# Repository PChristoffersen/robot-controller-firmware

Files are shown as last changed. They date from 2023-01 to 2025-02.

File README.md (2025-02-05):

# Robot Controller

Robot controller for use with [ROS](https://www.ros.org/) 

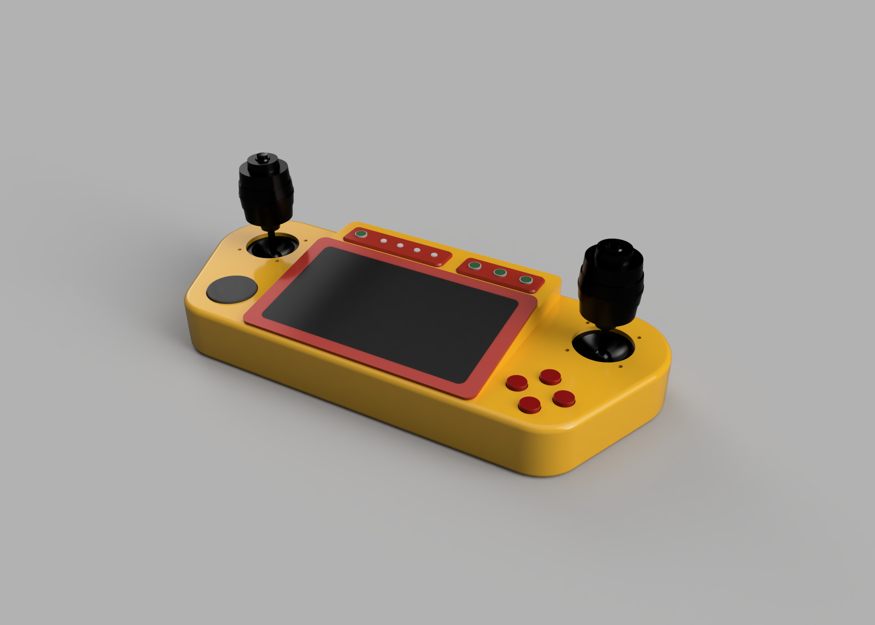
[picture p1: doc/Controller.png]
Controller

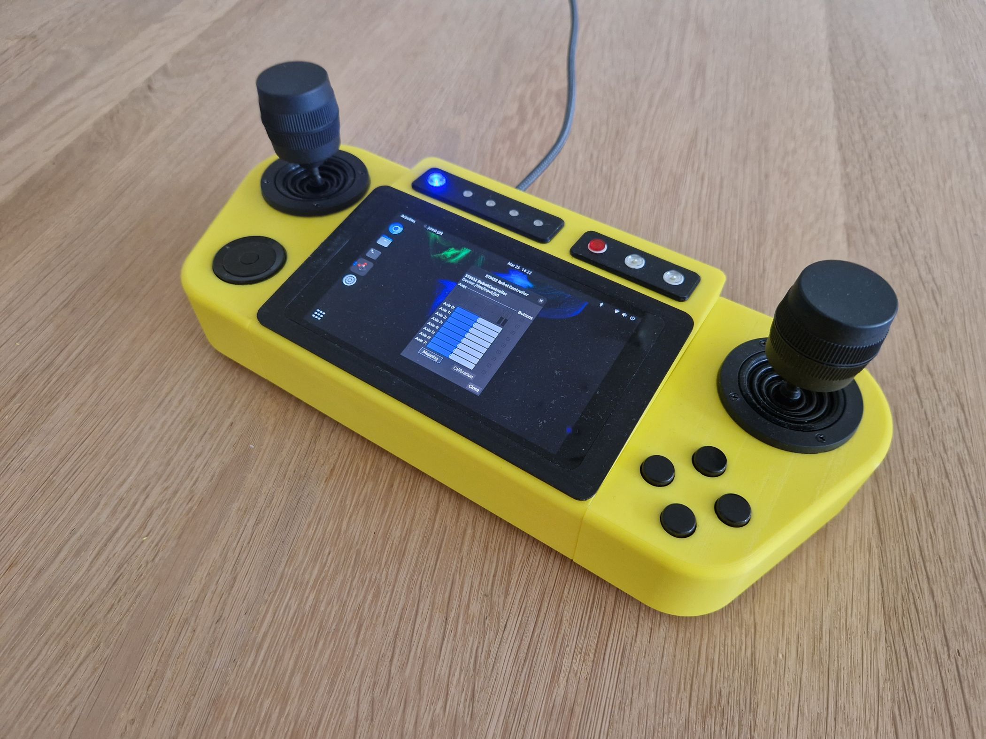
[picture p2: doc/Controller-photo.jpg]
Controller-Photo

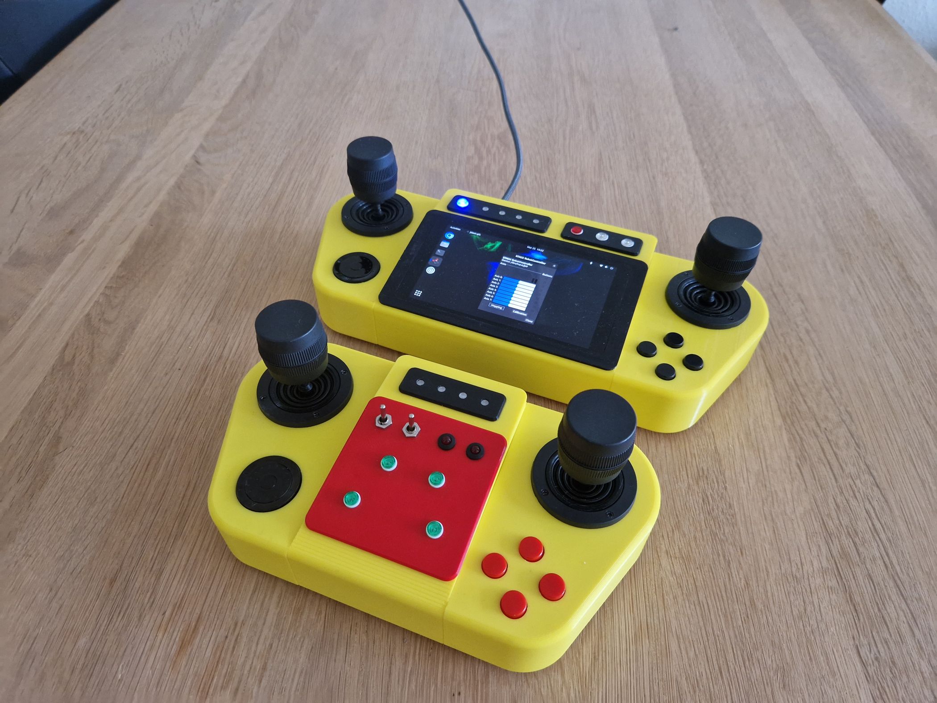
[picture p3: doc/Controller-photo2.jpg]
Controller-Photo


# Hardware

- [Waveshare 5.5inch AMOLED screen](https://www.waveshare.com/wiki/5.5inch_HDMI_AMOLED)
- Rasbperry Pi 4 or similar
- STM32F103 BluePill micro controller
- 2x JH-D300X-R4 3 Axis joystick
- [Adafruit ANO Rotary Encoder](https://learn.adafruit.com/ano-rotary-encoder)
- 4x [Sparkfun LED Tactile Button](https://www.sparkfun.com/products/10439)
- 4x [Sparkfun LED Tactile Button Breakout](https://www.sparkfun.com/products/10467)
- 4x 12mm Tactile Push button
- 4x [Adafruit RGB Smart NeoPixel](https://www.adafruit.com/product/1558)

# 3d Model

See [model](doc/model/)

# Schematic 

See documentation [schematic](doc/Schematic.pdf)

Button breakout board [gerber](doc/Button-breakout-board.zip)
Controller board [gerber](doc/Controller-board.zip)

# Lighting

TODO

# Microcontroller

## Pinout

|Function|Mode|Pin||Pin|Mode|Function|
|--- |--- |--- |---|--- |---  |--- |
| | | |USB| | | |
|ANO_SW5 |GPIO |PB12| |GND | | |
|ANO_SW4 |GPIO |PB13| |GND | | |
|ANO_SW3 |GPIO |PB14| |3V3 | | |
|ANO_SW2 |GPIO |PB15| |NRST| | |
|ANO_SW1 |GPIO |PA8 | |PB11|GPIO |EXT_OUT2 |
|DEBUG |UART1  |PA9 | |PB10|GPIO |EXT_OUT1 |
|DEBUG |UART1  |PA10| |PB1 |PWM  |LED4 |
|USB |USB |PA11| |PB0 |PWM  |LED3 |
|USB |USB |PA12| |PA7 |GPIO |EXT_IN2 |
|NEOPIXEL |PWM |PA15| |PA6 |ADC6 |VSENSE |
|ANO_ENCB |GPIO |PB3 | |PA5 |ADC5 |RIGHT_Z |
|ANO_ENCA |GPIO |PB4 | |PA4 |ADC4 |RIGHT_Y |
|EXT_IN1 |GPIO |PB5 | |PA3 |ADC3 |RIGHT_X |
|LED2 |PWM |PB6 | |PA2 |ADC2 |LEFT_Z |
|LED1 |PWM |PB7 | |PA1 |ADC1 |LEFT_Y |
|PCF8574_SCL|SCL1 |PB8 | |PA0 |ADC0 |LEFT_X |
|PCF8574_SDA|SDA1 |PB9 | |PC15|GPIO |PCF8574_INT|
| | |5V  | |PC14|GPIO |AUX |
| | |GND | |PC13| | |
| | |3V3 | |VBAT| | |

## PCF8574AN (i2c gpio expander)
|Pin|Function|
|---|---|
|0|RIGHT_X|
|1|RIGHT_Y|
|2|RIGHT_A|
|3|RIGHT_B|
|4|TOP_SW1|
|5|TOP_SW2|
|6|TOP_SW3|
|7|TOP_PWR_SW|

## Timer usage

|Timer|Usage|
|---|---|
|1|Unused|
|2|LED|
|3|PWM, led 1 and 2|
|4|PWM, led 2 and 4|

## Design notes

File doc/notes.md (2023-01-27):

# DMA1:
|Channel|Function|
|---|---|
|1|ADC1, TIM2_CH3, TIM4_CH1|
|2|USART3_TX, TIM1_CH1, TIM2_UP,  TIM3_CH3, SPI1_RX|
|3|USART3_RX, TIM1_CH2, TIM3_CH4, TIM3_UP,  SPI1_TX|
|4|USART1_TX, TIM1_CH4, TIM1_TRIG, TIM1_COM, TIM4_CH2, SPI2/I2S2_RX, |I2C2_TX
|5|USART1_RX, TIM1_UP, TIM2_CH1, TIM4_CH3, SPI2/I2S2_TX, I2C2_RX|
|6|USART2_RX, TIM1_CH3, TIM3_CH1, TIM3_TRIG, I2C1_TX|
|7|USART2_TX, TIM2_CH2, TIM2_CH4, TIM4_UP, I2C1_RX|

## Timer 1
|Timer|00|11|DMA|
|---|---|---|---|
|TIM1_CH1|PA8 |PE9 |2
|TIM1_CH2|PA9 |PE11|3
|TIM1_CH3|PA10|PE13|6
|TIM1_CH4|PA11|PE14|4

## Timer 2
|Timer|00|01|10|11|DMA|
|---|---|---|---|---|---|
|TIM2_CH1_ETR|PA0|PA15|PA0|PA15|5
|TIM2_CH2 |PA1|PB3 |PA1|PB3 |7
|TIM2_CH3 |PA2|PB10| | |1
|TIM2_CH4 |PA3|PB11| | |7

## Timer 3
|Timer|00|01|11|DMA|
|---|---|---|---|---|
|TIM3_CH1|PA6|PB4||6|
|TIM3_CH2|PA7|PB5|||
|TIM3_CH3|PB0|PC8||2|
|TIM3_CH4|PB1|PC9||3|

## Timer 4
|Timer|0|1|DMA|
|---|---|---|---|
|TIM4_CH1|PB6|PD12|1|
|TIM4_CH2|PB7|PD13|4|
|TIM4_CH3|PB8|PD14|5|
|TIM4_CH4|PB9|PD15||

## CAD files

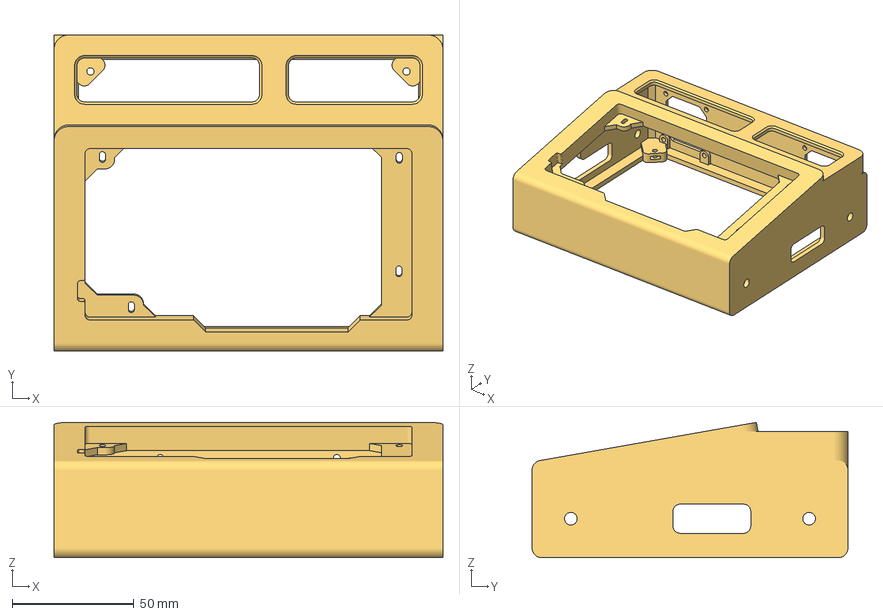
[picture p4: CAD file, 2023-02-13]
doc/model/Main.3mf
160.0 x 130.0 x 55.6 mm

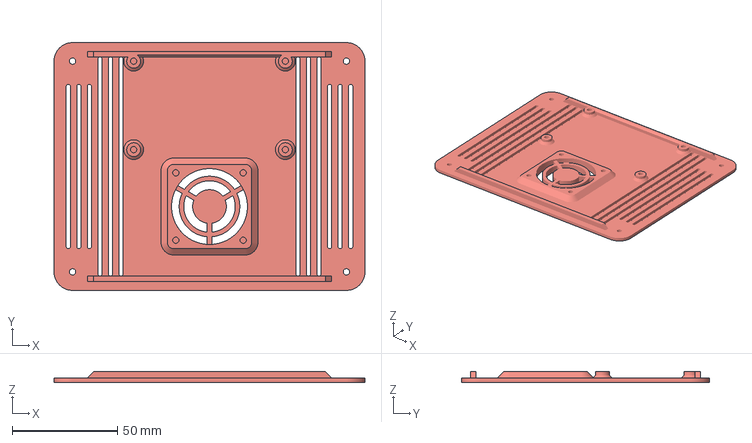
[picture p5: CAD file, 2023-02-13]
doc/model/Main Floor.3mf
147.6 x 117.6 x 5.00 mm

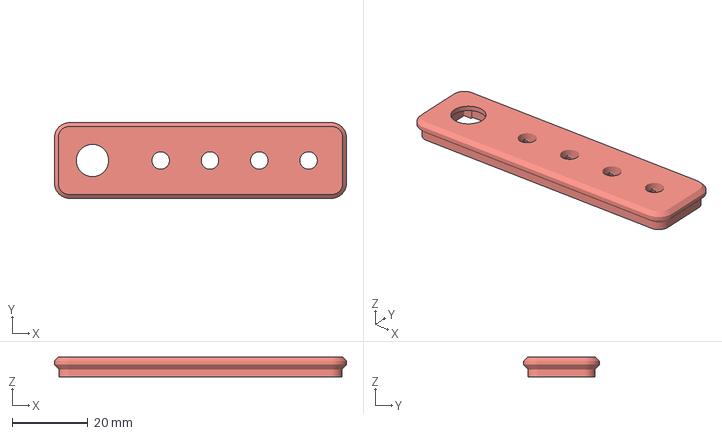
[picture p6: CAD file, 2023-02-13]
doc/model/ButtonBar Left.3mf
77.0 x 20.0 x 5.20 mm

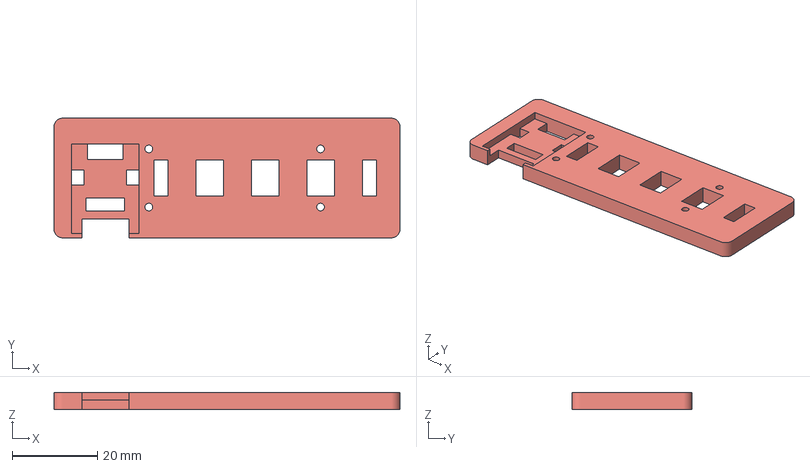
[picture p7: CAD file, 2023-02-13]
doc/model/ButtonBar Left lower.3mf
81.0 x 28.0 x 4.00 mm

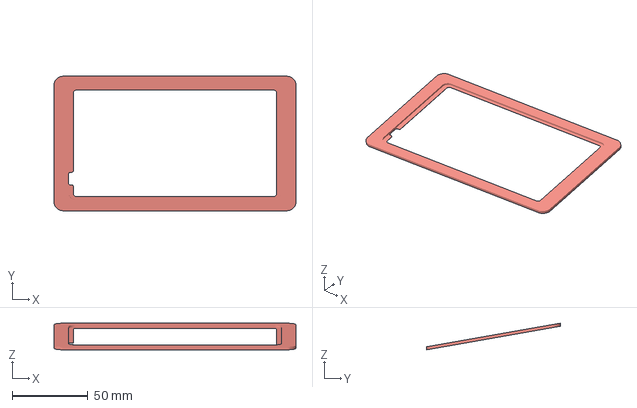
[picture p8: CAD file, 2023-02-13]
doc/model/Screen frame.3mf
160.0 x 89.0 x 17.6 mm

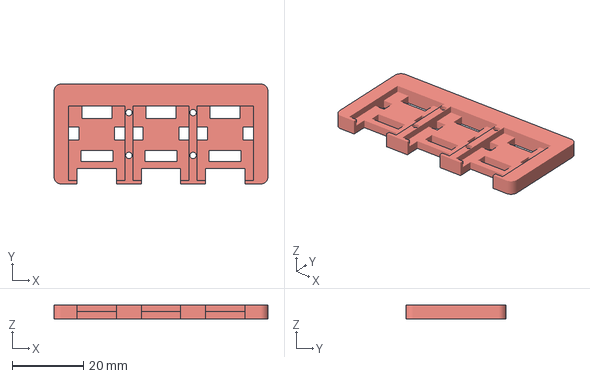
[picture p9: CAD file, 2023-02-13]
doc/model/ButtonBar Right lower.3mf
60.0 x 28.0 x 4.00 mm

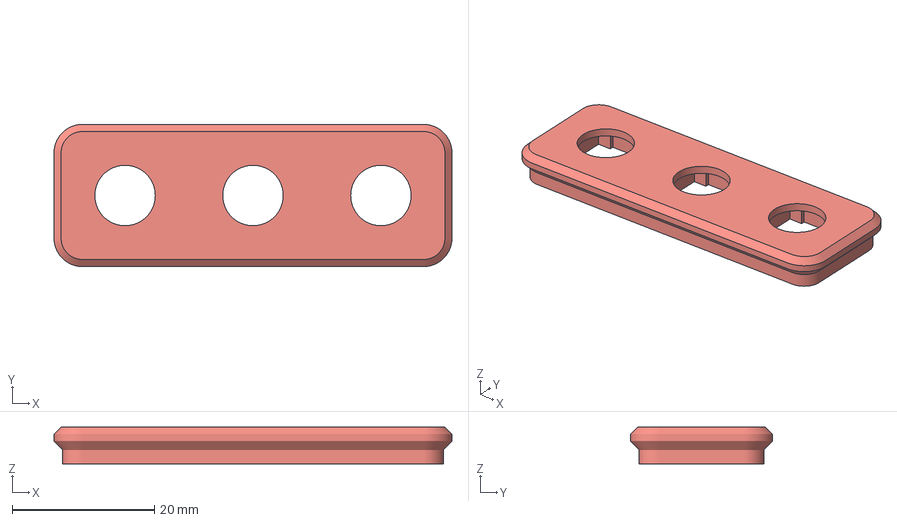
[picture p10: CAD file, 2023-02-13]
doc/model/ButtonBar Right.3mf
56.0 x 20.0 x 5.20 mm

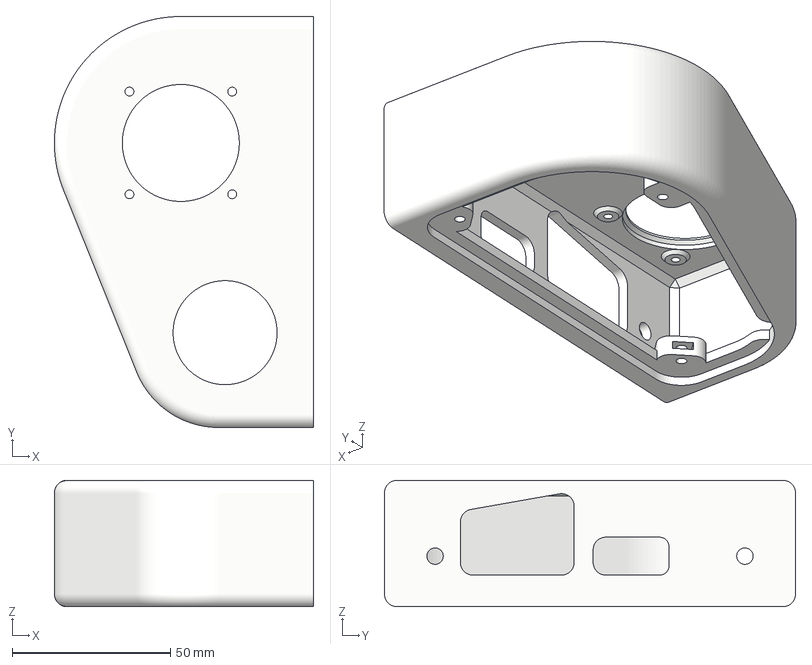
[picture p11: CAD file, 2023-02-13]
doc/model/Left Pod.3mf
82.0 x 130.0 x 40.0 mm

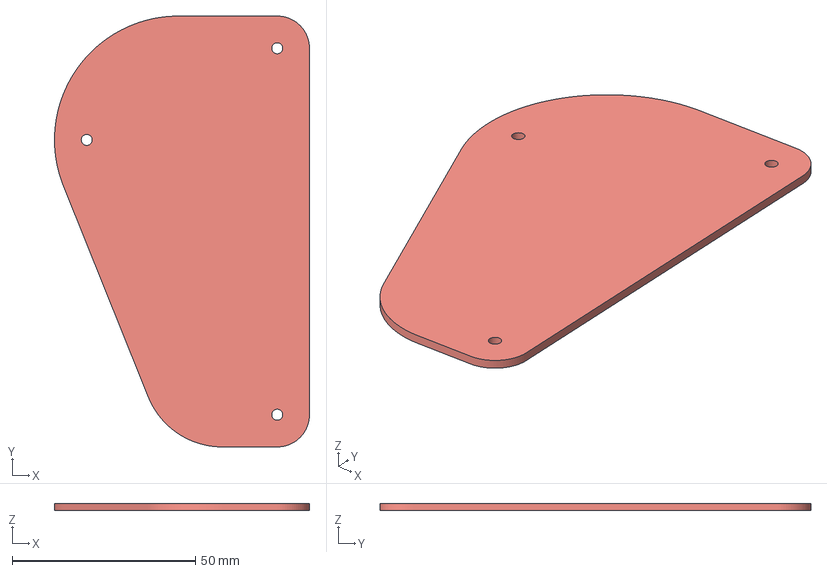
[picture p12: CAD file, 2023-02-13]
doc/model/Left Floor.3mf
69.6 x 117.6 x 2.00 mm

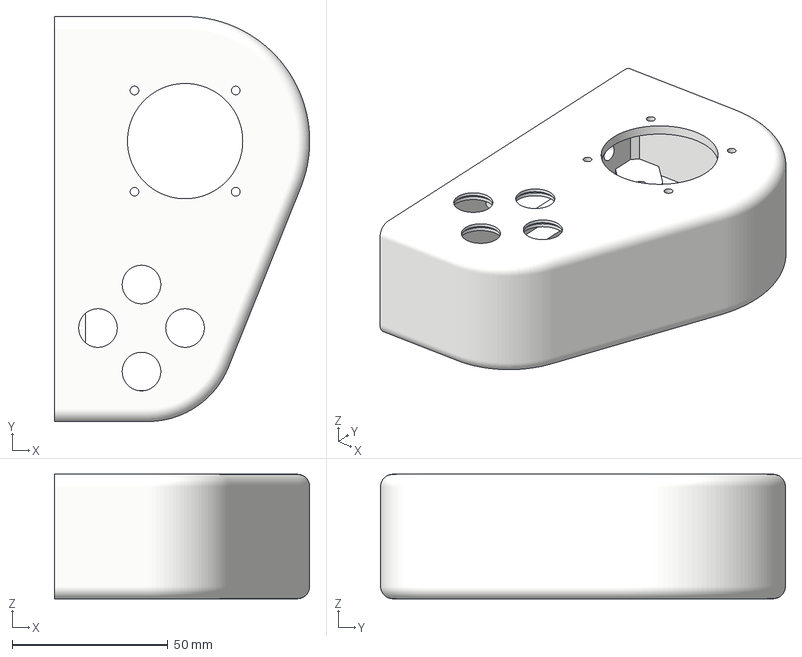
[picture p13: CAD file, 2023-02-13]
doc/model/Right Pod.3mf
82.0 x 130.0 x 40.0 mm

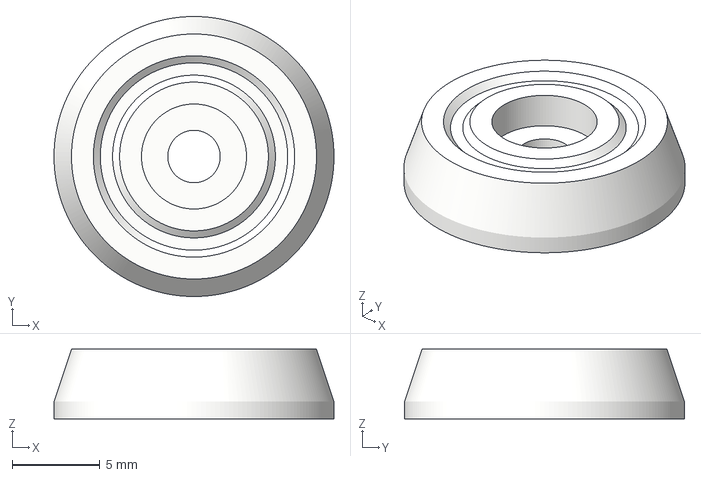
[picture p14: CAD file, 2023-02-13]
doc/model/Feet.3mf
16.0 x 16.0 x 4.00 mm

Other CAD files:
doc/model/Right Floor.3mf

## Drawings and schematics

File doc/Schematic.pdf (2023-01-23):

## Buttons

External control | MISC

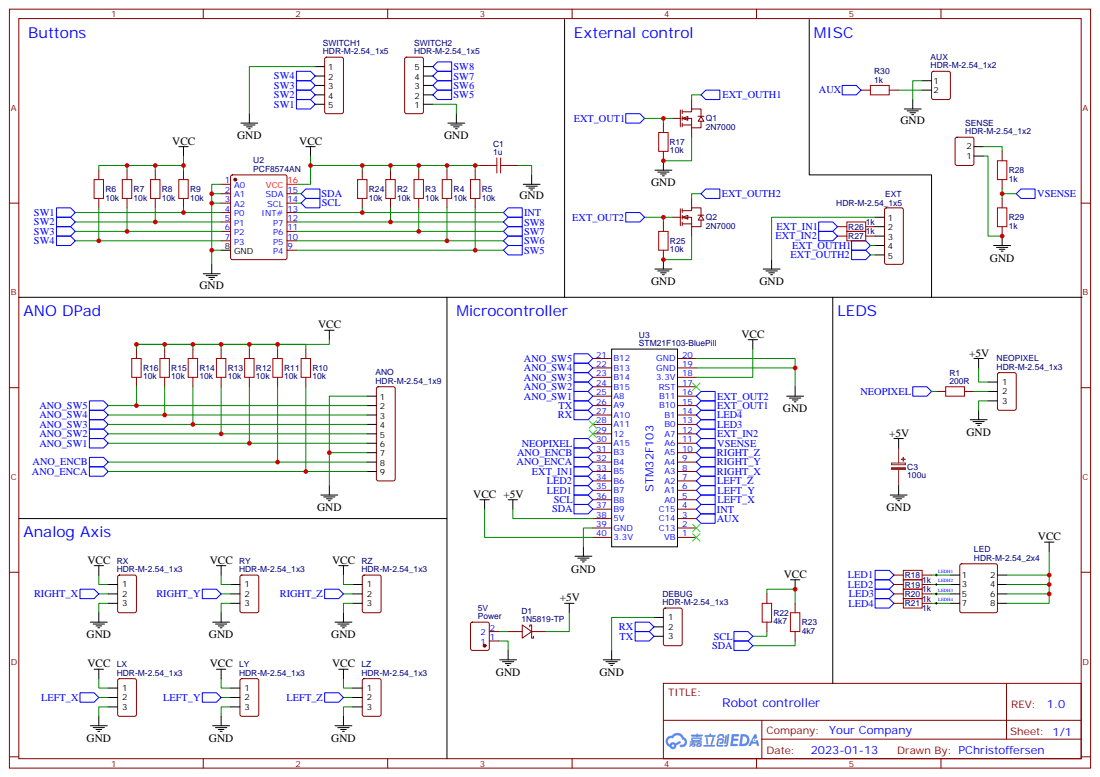
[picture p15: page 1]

P5 10 P6 11 P7 12 INT# 13 SCL 14 SDA 15 VCC 16

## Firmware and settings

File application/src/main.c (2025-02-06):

/**
 * BSD 3-Clause License
 * 
 * Copyright (c) 2025, Peter Christoffersen
 * 
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
 * 3. Neither the name of the copyright holder nor the names of its
 *    contributors may be used to endorse or promote products derived from
 *    this software without specific prior written permission.
 * 
 * THIS SOFTWARE IS PROVIDED BY THE COPYRIGHT HOLDERS AND CONTRIBUTORS "AS IS"
 * AND ANY EXPRESS OR IMPLIED WARRANTIES, INCLUDING, BUT NOT LIMITED TO, THE
 * IMPLIED WARRANTIES OF MERCHANTABILITY AND FITNESS FOR A PARTICULAR PURPOSE ARE
 * DISCLAIMED. IN NO EVENT SHALL THE COPYRIGHT HOLDER OR CONTRIBUTORS BE LIABLE
 * FOR ANY DIRECT, INDIRECT, INCIDENTAL, SPECIAL, EXEMPLARY, OR CONSEQUENTIAL
 * DAMAGES (INCLUDING, BUT NOT LIMITED TO, PROCUREMENT OF SUBSTITUTE GOODS OR
 * SERVICES; LOSS OF USE, DATA, OR PROFITS; OR BUSINESS INTERRUPTION) HOWEVER
 * CAUSED AND ON ANY THEORY OF LIABILITY, WHETHER IN CONTRACT, STRICT LIABILITY,
 * OR TORT (INCLUDING NEGLIGENCE OR OTHERWISE) ARISING IN ANY WAY OUT OF THE USE
 * OF THIS SOFTWARE, EVEN IF ADVISED OF THE POSSIBILITY OF SUCH DAMAGE.
 */

#include <stdio.h>
#include <string.h>

#include <zephyr/kernel.h>
#include <zephyr/version.h>
#include <zephyr/drivers/hwinfo.h>
#include <zephyr/input/input.h>
#include <zephyr/logging/log.h>

LOG_MODULE_REGISTER(main);

#include "controller.h"
#include "usb_device.h"
#include "hid_device.h"
#include "lamp_array.h"
#include "lighting.h"
#include "input_mapping.h"
#include "util.h"


K_MUTEX_DEFINE(g_input_mutex);
K_CONDVAR_DEFINE(g_input_cond);
K_CONDVAR_DEFINE(g_report_cond);

static hid_gamepad_input_t g_input_state = {
    .report_id = REPORT_ID_GAMEPAD,
    .dpad = 0xF,
};
static bool g_input_state_changed = false;

static led_state_t g_led_state = 0;

static uint32_t g_idle_duration = 0;

static bool g_enabled = false;
static bool g_autonomous = true;
static bool g_suspended = false;
static bool g_report_pending = false;
K_TIMER_DEFINE(g_report_timer, NULL, NULL);


static void update_leds(led_state_t state)
{
    for (uint8_t i=0; i<CONTROLLER_LED_COUNT; i++) {
        led_set(i, (state & (1<<i)) ? 100 : 0);
    }
}

static void start_report_timer()
{
    k_timer_start(&g_report_timer, K_MSEC(CONFIG_ROBOT_CONTROLLER_MIN_INPUT_REPORT_INTERVAL_MS), K_NO_WAIT);
}


/* -----------------------------------------------------------------------------------
 * State handling
 * ----------------------------------------------------------------------------------- */

void controller_reset()
{
    k_mutex_lock(&g_input_mutex, K_FOREVER);
    if (g_enabled) {
        LOG_INF("Controller Reset");
        update_leds(g_led_state);
        lamp_array_reset();
        g_idle_duration = 0;
        g_autonomous = true;
        g_led_state = 0;
        g_input_state_changed = true;
        start_report_timer();
        k_condvar_broadcast(&g_input_cond);
    }
    k_mutex_unlock(&g_input_mutex);
}

void controller_set_enabled(bool enabled)
{
    k_mutex_lock(&g_input_mutex, K_FOREVER);
    if (enabled != g_enabled) {
        LOG_INF("Controller %s", enabled?"enabled":"disabled");
        g_enabled = enabled;
        if (enabled) {
            start_report_timer();
        }
        k_condvar_broadcast(&g_input_cond);
    }
    k_mutex_unlock(&g_input_mutex);
}

void controller_set_suspend(bool suspended)
{
    k_mutex_lock(&g_input_mutex, K_FOREVER);
    if (suspended != g_suspended) {
        g_suspended = suspended;
        if (g_enabled) {
            LOG_INF("Controller %s", suspended?"suspended":"resumed");
            if (g_suspended) {
                g_autonomous = true;
                controller_set_idle(0);
                led_strip_clear();
                lamp_array_reset();
                update_leds(0x00);
            }
            else {
                if (g_autonomous) {
                    update_leds(g_led_state);
                }
                start_report_timer();
                g_input_state_changed = true;
            }
            k_condvar_broadcast(&g_input_cond);
        }
    }
    k_mutex_unlock(&g_input_mutex);
}



int controller_set_output(const uint8_t *buffer, uint16_t bufsize)
{
    if (bufsize < sizeof(hid_gamepad_output_t)) {
        return -EINVAL;
    }

    const hid_gamepad_output_t *output = (const hid_gamepad_output_t *)buffer;

    LOG_DBG("Set Output: leds=%02x", output->leds);
    k_mutex_lock(&g_input_mutex, K_FOREVER);
    if (g_led_state != output->leds) {
        g_led_state = output->leds;
        if (g_autonomous && !g_suspended) {
            update_leds(g_led_state);
        }
    }
    k_mutex_unlock(&g_input_mutex);

    return -ENOTSUP;
}


void controller_set_idle(const uint32_t duration)
{
    LOG_DBG("Set Idle: duration=%u", duration);
    k_mutex_lock(&g_input_mutex, K_FOREVER);
    if (g_idle_duration != duration) {
        g_idle_duration = duration;
        k_condvar_broadcast(&g_input_cond);
    }
    k_mutex_unlock(&g_input_mutex);
}


uint32_t controller_get_idle()
{
    LOG_DBG("Get Idle: duration=%u", g_idle_duration);
    return g_idle_duration;
}





void controller_set_autonomous_mode(bool enabled)
{
    k_mutex_lock(&g_input_mutex, K_FOREVER);
    if (enabled != g_autonomous) {
        g_autonomous = enabled;
        led_strip_clear();
        if (g_autonomous) {
            update_leds(g_led_state);
        }
        else {
            update_leds(0x00);
        }
    }
    k_mutex_unlock(&g_input_mutex);
}

bool controller_is_autonomous_mode()
{
    return g_autonomous;
}


void controller_input_report_done()
{
    k_mutex_lock(&g_input_mutex, K_FOREVER);
    g_report_pending = false;
    k_condvar_broadcast(&g_report_cond);
    k_mutex_unlock(&g_input_mutex);
}



/* -----------------------------------------------------------------------------------
 * Input Event handling
 * ----------------------------------------------------------------------------------- */

static void input_cb(struct input_event *event, void *user_data)
{
    if (k_mutex_lock(&g_input_mutex, K_MSEC(20)) != 0) {
        // Drop event if it takes too long to acquire the mutex
        return;
    }
    static dpad_state_t dpad_state = {0};
    switch (event->type) {
        case INPUT_EV_KEY:
            LOG_DBG("Key Event: code=0x%x, value=%d", event->code, event->value);
            g_input_state_changed |= input_process_key(event, &g_input_state, &dpad_state);
            break;
        case INPUT_EV_REL:
            LOG_DBG("Relative Event: code=0x%x, value=%d", event->code, event->value);
            g_input_state_changed |= input_process_dial(event, &g_input_state);
            break;
        case INPUT_EV_ABS:
            LOG_DBG("Absolute Event: code=0x%x, value=%d", event->code, event->value);
            g_input_state_changed |= input_process_axis(event, &g_input_state);
            break;
    }
    if (g_input_state_changed) {
        g_input_state.dpad = input_dpad_map(&dpad_state);
        k_condvar_broadcast(&g_input_cond);
    }
    k_mutex_unlock(&g_input_mutex);
}

INPUT_CALLBACK_DEFINE(NULL, input_cb, NULL);



/* -----------------------------------------------------------------------------------
 * Main loop
 * ----------------------------------------------------------------------------------- */

static void banner()
{
	printf("\n");
	printf("---------------------------------\n");
	printf("Zephyr OS version: %s\n", KERNEL_VERSION_STRING);
	printf("---------------------------------\n");
	printf("\n");

	print_reset_cause();
	hwinfo_clear_reset_cause();

	printf("\n\n");
}


int main(void)
{
    int ret;

	banner();

	lighting_init();
	controller_hid_device_init();
	controller_usb_device_init();

    // Initialization done - lower priority and start main loop
    k_thread_priority_set(k_current_get(), K_LOWEST_APPLICATION_THREAD_PRIO);

    k_mutex_lock(&g_input_mutex, K_FOREVER);
    start_report_timer();
    while (true) {
        if (!g_enabled || g_suspended) {
            LOG_DBG("Wait... enabled=%d, suspended=%d", g_enabled, g_suspended);
            k_mutex_unlock(&g_input_mutex);
            k_msleep(100);
            k_mutex_lock(&g_input_mutex, K_FOREVER);
            continue;
        }

        k_mutex_unlock(&g_input_mutex);
        k_timer_status_sync(&g_report_timer);
        k_mutex_lock(&g_input_mutex, K_FOREVER);

        // Wait for input event or idle timeout
        if (!g_input_state_changed) {
    		k_condvar_wait(&g_input_cond, &g_input_mutex, g_idle_duration>0 ? K_MSEC(g_idle_duration) : K_FOREVER);
        }
        if (!g_enabled || g_suspended) {
            continue;
        }

        if (g_input_state_changed || g_idle_duration>0) {
            LOG_DBG("Submit input_state_changed=%d idle_state=%u  enabled=%d,  suspended=%d", g_input_state_changed, g_idle_duration, g_enabled, g_suspended);
            
            // Wait for previous report to be sent
            while (g_report_pending) {
                k_condvar_wait(&g_report_cond, &g_input_mutex, K_FOREVER);
            }

            // Submit gamepad state
            ret = controller_hid_submit_gamepad((const uint8_t *)&g_input_state, sizeof(g_input_state));
            if (ret != 0) {
                LOG_ERR("Failed to submit gamepad state: %d", ret);
                break;
            }
            start_report_timer();
            g_input_state.dial = 0; // Reset dial relative value
            g_input_state_changed = false; // Clear input state change flag
            g_report_pending = true; // Set report pending flag
        }
    }
    k_mutex_unlock(&g_input_mutex);

	return 0;
}

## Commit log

2023-02-04 Misc - Ano button mapping bug fix - Enabled watchdog - Added demo.sh
2023-02-13 Added 3d models
    [ButtonBar Left lower.3mf, ButtonBar Left.3mf, ButtonBar Right lower.3mf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]
2023-03-28 Added extra HID buttons
2025-02-05 Squashed commit of the following:
    commit 4124065c9bb099942e5733f18423f4eb181d5f8d
    Author: Peter Christoffersen <pch@plyt.dk>
    Date: Wed Feb 5 06:21:15 2025 +0000
    usbd API change fix
    commit eb5bb3f95b1e29ff3a04cccc19b6d146306f8188
    Author: Peter Christoffersen <pch@plyt.dk>
    Date: Tue Feb 4 20:42:05 2025 +0000
    More complete Zephyr migration
    commit 6449049df943c625cd42d6bbb744ba956ec69c73
    Merge: 7c3c227 db42b76
    Author: Peter Christoffersen <pch@plyt.dk>
    Date: Tue Feb 4 20:32:11 2025 +0000
    Merge branch 'main' of github.com:PChristoffersen/robot-controller-firmware
    commit 7c3c227437f2e5b45fd4500f9a1920921896ff4b
    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
    [controller.h]
